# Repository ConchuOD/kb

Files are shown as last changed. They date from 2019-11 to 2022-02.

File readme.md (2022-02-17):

# Custom keyboard

Things that are sub-optimal:
- mounting holes are M2 when M3 would be better.
- SOD323 are needlessly small, requiring better soldering gear than is reasonable.

Thanks to Jorge Reyes for his simple T3.2 model: https://grabcad.com/library/teensy-3-1-3-2-1
Thanks also to Constantin for his eagle teensy models that I converted to use in kicad https://forum.pjrc.com/threads/24637-Updated-Teensy-3-1-and-Teensy-3-0-Eagle-libraries

After 2 years, I finally got myself a 3d printer. I might finally finish this :)

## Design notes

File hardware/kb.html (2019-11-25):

# G:\desktop\keyboard\kicad\kb.sch

24/11/2019 17:05:27

Eeschema (5.1.4)-1

Component Count:187

Ref | Qnty | Value | Part | Datasheet | Description | Vendor
A95, B95, BCKT95, BSLH95, C95, COLON95, COMMA95, D95, E95, EIGHT95, EQL95, ESC95, F1, F2, F3, F4, F5, F6, F7, F8, F9, F10, F11, F12, F95, FIVE95, FOUR95, FSH95, FSTOP95, G95, H95, HASH95, I95, J95, K95, L95, LSB95, M95, MINUS95, N1, N2, N3, N4, N5, N6, N7, N8, N9, N95, NDOT95, NINE95, NINUS95, NSLSH95, NSTAR95, NUMLK95, NZERO95, NZZERO95, O95, ONE95, P95, Q95, R95, RSB95, S95, SEVEN95, SIX95, T95, THREE95, TICK95, TWO95, U95, V95, W95, X95, Y95, Z95, ZERO95 | 77 | CHERRY-MX | kb:CHERRYMX_CHERRY-MX
BKSP95, TAB95 | 2 | CHERRY-MX | kb:CHERRYMX_CHERRY-MX
CAPS95 | 1 | CHERRY-MX | kb:CHERRYMX_CHERRY-MX
D1, D2, D3, D4, D5, D6, D7, D8, D9, D10, D11, D12, D13, D14, D15, D16, D17, D18, D19, D20, D21, D22, D23, D24, D25, D26, D27, D28, D29, D30, D31, D32, D33, D34, D35, D36, D37, D38, D39, D40, D41, D42, D43, D44, D45, D46, D47, D48, D49, D50, D51, D52, D53, D54, D55, D56, D57, D58, D59, D60, D61, D62, D63, D64, D65, D66, D67, D68, D69, D70, D71, D72, D73, D74, D75, D76, D77, D78, D79, D80, D81, D82, D84, D85, D86, D87, D88, D89, D90, D91, D92, D93, D94 | 93 | 1N4148WS | kb:DIODES_1N4148WS
ENTER95 | 1 | CHERRY-MX | kb:CHERRYMX_CHERRY-MX
FN95, LALT95, LCTRL95, LOS95, LSHFT95, RALT95, RCTRL95, ROS95, RSHFT95 | 9 | CHERRY-MX | kb:CHERRYMX_CHERRY-MX
NNTER95, NPLUS95 | 2 | CHERRY-MX | kb:CHERRYMX_CHERRY-MX
SPACE95 | 1 | CHERRY-MX | kb:CHERRYMX_CHERRY-MX
U$1 | 1 | TEENSY_3.1-3.2_OUTER_ROW | kb:TEENSY_3_AND_LC_SERIES_BOARDS_V1.4_TEENSY_3.1-3.2_OUTER_ROW

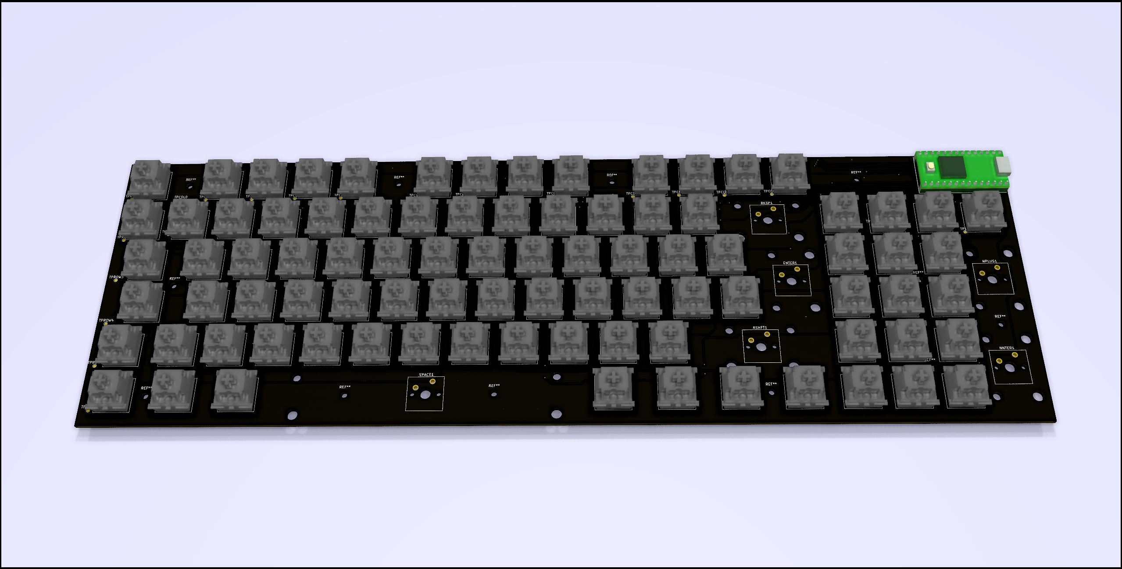
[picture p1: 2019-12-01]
hardware/kb.png

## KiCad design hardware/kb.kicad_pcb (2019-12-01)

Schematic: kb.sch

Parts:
A1: CHERRY-MX; SW_Cherry_MX_1.00u_PCB
B1: CHERRY-MX; SW_Cherry_MX_1.00u_PCB
BCKT1: CHERRY-MX; SW_Cherry_MX_1.00u_PCB
BKSP1: CHERRY-MX; SW_Cherry_MX_2.00u_PCB
BSLH1: CHERRY-MX; SW_Cherry_MX_1.00u_PCB
C1: CHERRY-MX; SW_Cherry_MX_1.00u_PCB
CAPS1: CHERRY-MX; SW_Cherry_MX_1.75u_PCB
COLON1: CHERRY-MX; SW_Cherry_MX_1.00u_PCB
COMMA1: CHERRY-MX; SW_Cherry_MX_1.00u_PCB
D1, D2, D3, D4, D5, D6, D7, D8, D9, D10, D11, D12, D13, D14, D15, D16, D17, D18, D19, D20, D21, D22, D23, D24, D25, D26, D27, D28, D29, D30, D31, D32, D33, D34, D35, D36, D37, D38, D39, D40, D41, D42, D43, D44, D45, D46, D47, D48, D49, D50, D51, D52, D53, D54, D55, D56, D57, D58, D59, D60, D61, D62, D63, D64, D65, D66, D67, D68, D69, D70, D71, D72, D73, D74, D75, D76, D77, D78, D79, D80, D81, D82, D84, D85, D86, D87, D88, D89, D90, D91, D92, D93, D94: 1N4148WS; DIODES_SOD-323
D83: CHERRY-MX; SW_Cherry_MX_1.00u_PCB
E1: CHERRY-MX; SW_Cherry_MX_1.00u_PCB
EIGHT1: CHERRY-MX; SW_Cherry_MX_1.00u_PCB
ENTER1: CHERRY-MX; SW_Cherry_MX_ISOEnter_PCB
EQL1: CHERRY-MX; SW_Cherry_MX_1.00u_PCB
ESC1: CHERRY-MX; SW_Cherry_MX_1.00u_PCB
F1, F2, F3, F4, F5, F6, F7, F8, F9, F10, F11, F12, F13: CHERRY-MX; SW_Cherry_MX_1.00u_PCB
FIVE1: CHERRY-MX; SW_Cherry_MX_1.00u_PCB
FN1: CHERRY-MX; SW_Cherry_MX_1.25u_PCB
FOUR1: CHERRY-MX; SW_Cherry_MX_1.00u_PCB
FSH1: CHERRY-MX; SW_Cherry_MX_1.00u_PCB
FSTOP1: CHERRY-MX; SW_Cherry_MX_1.00u_PCB
G1: CHERRY-MX; SW_Cherry_MX_1.00u_PCB
H1: CHERRY-MX; SW_Cherry_MX_1.00u_PCB
HASH1: CHERRY-MX; SW_Cherry_MX_1.00u_PCB
I1: CHERRY-MX; SW_Cherry_MX_1.00u_PCB
J1: CHERRY-MX; SW_Cherry_MX_1.00u_PCB
K1: CHERRY-MX; SW_Cherry_MX_1.00u_PCB
L1: CHERRY-MX; SW_Cherry_MX_1.00u_PCB
LALT1: CHERRY-MX; SW_Cherry_MX_1.25u_PCB
LCTRL1: CHERRY-MX; SW_Cherry_MX_1.25u_PCB
LOS1: CHERRY-MX; SW_Cherry_MX_1.25u_PCB
LSB1: CHERRY-MX; SW_Cherry_MX_1.00u_PCB
LSHFT1: CHERRY-MX; SW_Cherry_MX_1.25u_PCB
M1: CHERRY-MX; SW_Cherry_MX_1.00u_PCB
MINUS1: CHERRY-MX; SW_Cherry_MX_1.00u_PCB
N1, N2, N3, N4, N5, N6, N7, N8, N9, N10: CHERRY-MX; SW_Cherry_MX_1.00u_PCB
NDOT1: CHERRY-MX; SW_Cherry_MX_1.00u_PCB
NINE1: CHERRY-MX; SW_Cherry_MX_1.00u_PCB
NINUS1: CHERRY-MX; SW_Cherry_MX_1.00u_PCB
NNTER1: CHERRY-MX; SW_Cherry_MX_2.00u_Vertical_PCB
NPLUS1: CHERRY-MX; SW_Cherry_MX_2.00u_Vertical_PCB
NSLSH1: CHERRY-MX; SW_Cherry_MX_1.00u_PCB
NSTAR1: CHERRY-MX; SW_Cherry_MX_1.00u_PCB
NUMLK1: CHERRY-MX; SW_Cherry_MX_1.00u_PCB
NZERO1: CHERRY-MX; SW_Cherry_MX_1.00u_PCB
NZZERO1: CHERRY-MX; SW_Cherry_MX_1.00u_PCB
O1: CHERRY-MX; SW_Cherry_MX_1.00u_PCB
ONE1: CHERRY-MX; SW_Cherry_MX_1.00u_PCB
P1: CHERRY-MX; SW_Cherry_MX_1.00u_PCB
Q1: CHERRY-MX; SW_Cherry_MX_1.00u_PCB
R1: CHERRY-MX; SW_Cherry_MX_1.00u_PCB
RALT1: CHERRY-MX; SW_Cherry_MX_1.25u_PCB
RCTRL1: CHERRY-MX; SW_Cherry_MX_1.25u_PCB
ROS1: CHERRY-MX; SW_Cherry_MX_1.25u_PCB
RSB1: CHERRY-MX; SW_Cherry_MX_1.00u_PCB
RSHFT1: CHERRY-MX; SW_Cherry_MX_2.75u_PCB
S1: CHERRY-MX; SW_Cherry_MX_1.00u_PCB
SEVEN1: CHERRY-MX; SW_Cherry_MX_1.00u_PCB
SIX1: CHERRY-MX; SW_Cherry_MX_1.00u_PCB
SPACE1: CHERRY-MX; SW_Cherry_MX_6.25u_PCB
T1: CHERRY-MX; SW_Cherry_MX_1.00u_PCB
T32: TEENSY_3.1-3.2_DIL; TEENSY_3.0-3.2&LC_DIL
TAB1: CHERRY-MX; SW_Cherry_MX_1.50u_PCB
THREE1: CHERRY-MX; SW_Cherry_MX_1.00u_PCB
TICK1: CHERRY-MX; SW_Cherry_MX_1.00u_PCB
TP13: TestPoint; TestPoint_Pad_D1.0mm
TPCOL0, TPCOL1, TPCOL2, TPCOL3, TPCOL4, TPCOL5, TPCOL6, TPCOL7, TPCOL8, TPCOL9, TPCOL10, TPCOL11, TPCOL12: TestPoint; TestPoint_Pad_D1.0mm
TPROW0, TPROW1, TPROW2, TPROW3, TPROW4, TPROW5, TPROW6: TestPoint; TestPoint_Pad_D1.0mm
TWO1: CHERRY-MX; SW_Cherry_MX_1.00u_PCB
U1: CHERRY-MX; SW_Cherry_MX_1.00u_PCB
V1: CHERRY-MX; SW_Cherry_MX_1.00u_PCB
W1: CHERRY-MX; SW_Cherry_MX_1.00u_PCB
X1: CHERRY-MX; SW_Cherry_MX_1.00u_PCB
Y1: CHERRY-MX; SW_Cherry_MX_1.00u_PCB
Z1: CHERRY-MX; SW_Cherry_MX_1.00u_PCB
ZERO1: CHERRY-MX; SW_Cherry_MX_1.00u_PCB

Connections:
+3V3: T32.3.3V
+5V: T32.VIN
/COL0: D1.C, D2.C, D3.C, D4.C, D5.C, D6.C, D8.C, T32.0 (0/RX1/T), TPCOL0.1
/COL1: D7.C, D9.C, D10.C, D11.C, D12.C, D13.C, D14.C, T32.1 (1/TX1/T), TPCOL1.1
/COL2: D15.C, D16.C, D17.C, D18.C, D19.C, D20.C, D22.C, T32.2, TPCOL2.1
/COL3: D21.C, D24.C, D25.C, D26.C, D27.C, D28.C, D62.C, T32.3 (3/CAN-TX/PWM), TPCOL3.1
/COL4: D29.C, D30.C, D31.C, D32.C, D33.C, D34.C, D61.C, T32.4 (4/CAN-RX/PWM), TPCOL4.1
/COL5: D23.C, D35.C, D60.C, D64.C, D65.C, D66.C, D67.C, T32.5 (5/PWM), TPCOL5.1
/COL6: D36.C, D37.C, D38.C, D39.C, D40.C, D63.C, T32.6 (6/PWM), TPCOL6.1
/COL7: D42.C, D43.C, D44.C, D45.C, D46.C, T32.7 (7/RX3), TPCOL7.1
/COL8: D48.C, D49.C, D50.C, D51.C, D52.C, D53.C, T32.8 (8/TX3), TPCOL8.1
/COL9: D54.C, D55.C, D56.C, D57.C, D58.C, D59.C, D74.C, T32.9 (9/RX2/PWM), TPCOL9.1
/COL10: D69.C, D70.C, D71.C, D72.C, D77.C, D79.C, D80.C, T32.10 (10/TX2/PWM), TPCOL10.1
/COL11: D41.C, D47.C, D75.C, D76.C, D84.C, D85.C, D86.C, T32.11 (11/MOSI), TPCOL11.1
/COL12: D87.C, D88.C, D89.C, D90.C, D91.C, D92.C, T32.12 (12/MISO), TPCOL12.1
/COL13: D68.C, D73.C, D78.C, D81.C, D82.C, D93.C, D94.C, T32.13 (13/SCK/LED), TP13.1
/N$1: D1.A, ESC1.SW2 (PIN-2)
/N$2: BCKT1.SW2 (PIN-2), D2.A
/N$3: D3.A, TAB1.SW2 (PIN-2)
/N$4: CAPS1.SW2 (PIN-2), D4.A
/N$5: D5.A, LSHFT1.SW2 (PIN-2)
/N$6: D6.A, LCTRL1.SW2 (PIN-2)
/N$7: D8.A, ONE1.SW2 (PIN-2)
/N$8: D9.A, Q1.SW2 (PIN-2)
/N$9: A1.SW2 (PIN-2), D10.A
/N$10: BSLH1.SW2 (PIN-2), D11.A
/N$11: D12.A, LOS1.SW2 (PIN-2)
/N$12: D13.A, TWO1.SW2 (PIN-2)
/N$13: D14.A, W1.SW2 (PIN-2)
/N$14: D15.A, S1.SW2 (PIN-2)
/N$15: D16.A, Z1.SW2 (PIN-2)
/N$16: D17.A, LALT1.SW2 (PIN-2)
/N$17: D7.A, F1.SW2 (PIN-2)
/N$18: D19.A, THREE1.SW2 (PIN-2)
/N$19: D20.A, E1.SW2 (PIN-2)
/N$20: D21.A, D83.SW2 (PIN-2)
/N$21: D22.A, X1.SW2 (PIN-2)
/N$22: D29.A, SIX1.SW2 (PIN-2)
/N$23: D18.A, F2.SW2 (PIN-2)
/N$24: D25.A, FOUR1.SW2 (PIN-2)
/N$25: D26.A, R1.SW2 (PIN-2)
/N$26: D27.A, F13.SW2 (PIN-2)
/N$27: C1.SW2 (PIN-2), D28.A
/N$28: D35.A, Y1.SW2 (PIN-2)
/N$29: D24.A, F3.SW2 (PIN-2)
/N$30: D31.A, FIVE1.SW2 (PIN-2)
/N$31: D32.A, T1.SW2 (PIN-2)
/N$32: D33.A, G1.SW2 (PIN-2)
/N$33: D34.A, V1.SW2 (PIN-2)
/N$34: D60.A, H1.SW2 (PIN-2)
/N$35: D30.A, F4.SW2 (PIN-2)
/N$36: D37.A, EIGHT1.SW2 (PIN-2)
/N$37: D38.A, I1.SW2 (PIN-2)
/N$38: D39.A, K1.SW2 (PIN-2)
/N$39: D40.A, M1.SW2 (PIN-2)
/N$40: D41.A, NUMLK1.SW2 (PIN-2)
/N$41: D36.A, F7.SW2 (PIN-2)
/N$42: D43.A, NINE1.SW2 (PIN-2)
/N$43: D44.A, O1.SW2 (PIN-2)
/N$44: D45.A, L1.SW2 (PIN-2)
/N$45: COMMA1.SW2 (PIN-2), D46.A
/N$46: D47.A, NZERO1.SW2 (PIN-2)
/N$47: D42.A, F8.SW2 (PIN-2)
/N$48: D49.A, ZERO1.SW2 (PIN-2)
/N$49: D50.A, P1.SW2 (PIN-2)
/N$50: COLON1.SW2 (PIN-2), D51.A
/N$51: D52.A, FSTOP1.SW2 (PIN-2)
/N$52: D53.A, RALT1.SW2 (PIN-2)
/N$53: D48.A, F9.SW2 (PIN-2)
/N$54: D55.A, MINUS1.SW2 (PIN-2)
/N$55: D56.A, LSB1.SW2 (PIN-2)
/N$56: D57.A, TICK1.SW2 (PIN-2)
/N$57: D58.A, FSH1.SW2 (PIN-2)
/N$58: D59.A, ROS1.SW2 (PIN-2)
/N$59: D54.A, F10.SW2 (PIN-2)
/N$60: B1.SW2 (PIN-2), D61.A
/N$61: D62.A, SPACE1.SW2 (PIN-2)
/N$62: D23.A, F5.SW2 (PIN-2)
/N$63: D64.A, SEVEN1.SW2 (PIN-2)
/N$64: D65.A, U1.SW2 (PIN-2)
/N$65: D66.A, J1.SW2 (PIN-2)
/N$66: D67.A, N10.SW2 (PIN-2)
/N$67: D68.A, NDOT1.SW2 (PIN-2)
/N$68: D63.A, F6.SW2 (PIN-2)
/N$69: D70.A, EQL1.SW2 (PIN-2)
/N$70: D71.A, RSB1.SW2 (PIN-2)
/N$71: D72.A, HASH1.SW2 (PIN-2)
/N$72: D78.A, NPLUS1.SW2 (PIN-2)
/N$73: D74.A, FN1.SW2 (PIN-2)
/N$74: D69.A, F11.SW2 (PIN-2)
/N$75: BKSP1.SW2 (PIN-2), D76.A
/N$76: D77.A, ENTER1.SW2 (PIN-2)
/N$77: D81.A, N9.SW2 (PIN-2)
/N$78: D79.A, RSHFT1.SW2 (PIN-2)
/N$79: D80.A, RCTRL1.SW2 (PIN-2)
/N$80: D75.A, F12.SW2 (PIN-2)
/N$81: D82.A, N6.SW2 (PIN-2)
/N$83: D84.A, N7.SW2 (PIN-2)
/N$84: D85.A, N4.SW2 (PIN-2)
/N$85: D86.A, N1.SW2 (PIN-2)
/N$86: D93.A, N3.SW2 (PIN-2)
/N$87: D88.A, NSLSH1.SW2 (PIN-2)
/N$88: D89.A, N8.SW2 (PIN-2)
/N$89: D90.A, N5.SW2 (PIN-2)
/N$90: D91.A, N2.SW2 (PIN-2)
/N$91: D92.A, NZZERO1.SW2 (PIN-2)
/N$92: D87.A, NSTAR1.SW2 (PIN-2)
/N$93: D94.A, NNTER1.SW2 (PIN-2)
/N$94: D73.A, NINUS1.SW2 (PIN-2)
/ROW0: ESC1.SW1 (PIN-1), F1.SW1 (PIN-1), F2.SW1 (PIN-1), F3.SW1 (PIN-1), F4.SW1 (PIN-1), F5.SW1 (PIN-1), F6.SW1 (PIN-1), F8.SW1 (PIN-1), F9.SW1 (PIN-1), F10.SW1 (PIN-1), F11.SW1 (PIN-1), F12.SW1 (PIN-1), NINUS1.SW1 (PIN-1), NSTAR1.SW1 (PIN-1), T32.17/A3 (17/A3/T), TPROW0.1
/ROW1: BKSP1.SW1 (PIN-1), EQL1.SW1 (PIN-1), F7.SW1 (PIN-1), FIVE1.SW1 (PIN-1), FOUR1.SW1 (PIN-1), MINUS1.SW1 (PIN-1), NINE1.SW1 (PIN-1), NPLUS1.SW1 (PIN-1), NSLSH1.SW1 (PIN-1), ONE1.SW1 (PIN-1), SEVEN1.SW1 (PIN-1), T32.18/A4 (18/A4/T/SDA0), THREE1.SW1 (PIN-1), TPROW1.1, TWO1.SW1 (PIN-1), ZERO1.SW1 (PIN-1)
/ROW2: BCKT1.SW1 (PIN-1), E1.SW1 (PIN-1), EIGHT1.SW1 (PIN-1), LSB1.SW1 (PIN-1), N8.SW1 (PIN-1), N9.SW1 (PIN-1), NUMLK1.SW1 (PIN-1), O1.SW1 (PIN-1), P1.SW1 (PIN-1), R1.SW1 (PIN-1), RSB1.SW1 (PIN-1), SIX1.SW1 (PIN-1), T32.19/A5 (19/A5/T/SCL0), TPROW2.1, W1.SW1 (PIN-1), Y1.SW1 (PIN-1)
/ROW3: COLON1.SW1 (PIN-1), D83.SW1 (PIN-1), ENTER1.SW1 (PIN-1), I1.SW1 (PIN-1), L1.SW1 (PIN-1), N5.SW1 (PIN-1), N6.SW1 (PIN-1), N7.SW1 (PIN-1), Q1.SW1 (PIN-1), S1.SW1 (PIN-1), T1.SW1 (PIN-1), T32.20/A6 (20/A6/PWM), TAB1.SW1 (PIN-1), TICK1.SW1 (PIN-1), TPROW3.1, U1.SW1 (PIN-1)
/ROW4: A1.SW1 (PIN-1), CAPS1.SW1 (PIN-1), COMMA1.SW1 (PIN-1), F13.SW1 (PIN-1), FSH1.SW1 (PIN-1), FSTOP1.SW1 (PIN-1), G1.SW1 (PIN-1), H1.SW1 (PIN-1), HASH1.SW1 (PIN-1), K1.SW1 (PIN-1), N2.SW1 (PIN-1), N3.SW1 (PIN-1), N4.SW1 (PIN-1), T32.21/A7 (21/A7/PWM), TPROW4.1, Z1.SW1 (PIN-1)
/ROW5: BSLH1.SW1 (PIN-1), C1.SW1 (PIN-1), J1.SW1 (PIN-1), LSHFT1.SW1 (PIN-1), M1.SW1 (PIN-1), N1.SW1 (PIN-1), NNTER1.SW1 (PIN-1), NZZERO1.SW1 (PIN-1), RALT1.SW1 (PIN-1), ROS1.SW1 (PIN-1), RSHFT1.SW1 (PIN-1), T32.22/A8 (22/A8/T/PWM), TPROW5.1, V1.SW1 (PIN-1), X1.SW1 (PIN-1)
/ROW6: B1.SW1 (PIN-1), FN1.SW1 (PIN-1), LALT1.SW1 (PIN-1), LCTRL1.SW1 (PIN-1), LOS1.SW1 (PIN-1), N10.SW1 (PIN-1), NDOT1.SW1 (PIN-1), NZERO1.SW1 (PIN-1), RCTRL1.SW1 (PIN-1), SPACE1.SW1 (PIN-1), T32.23/A9 (23/A9/T/PWM), TPROW6.1
GND: T32.AGND, T32.GND

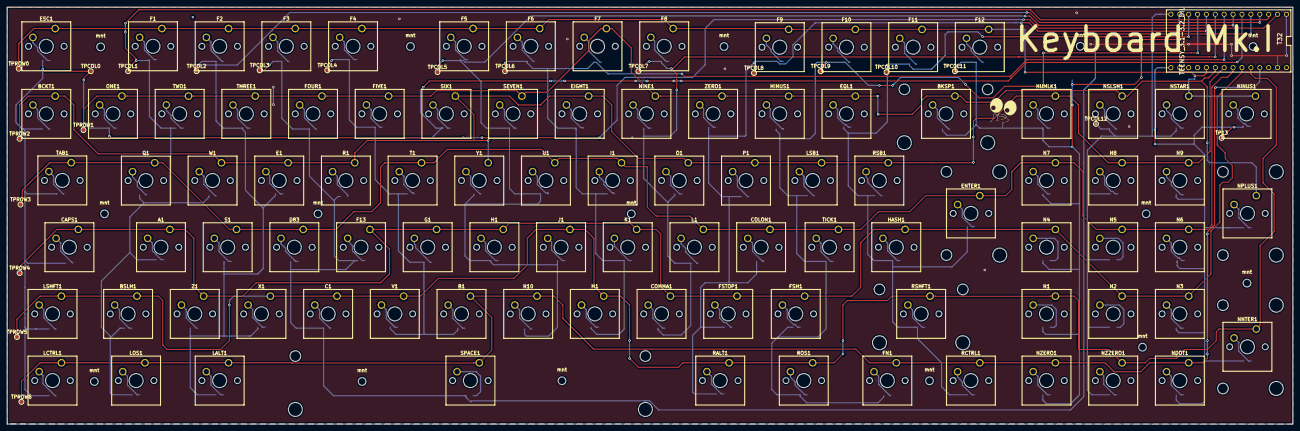
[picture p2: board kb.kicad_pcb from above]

Board: 2 copper layers, 367.3 x 119.1 mm, 223 parts (0 on the bottom side), 115 nets.

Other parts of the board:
mnt: MountingHole_2.2mm_M2
mnt#2, mnt#3, mnt#4, mnt#5, mnt#6, mnt#7, mnt#8, mnt#9, mnt#10, mnt#11, mnt#12, mnt#13, mnt#14, mnt#15: MountingHole_2.2mm_M2

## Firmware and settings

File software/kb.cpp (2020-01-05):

/* includes */
#include "tester.h"
#include "kb_matrix.h"
#include <Arduino.h>
#include "usb_kb.h"

/* defines */
#define SERIAL_BAUD_RATE 115200
#define DEBOUNCE_COUNT   4

int main(void)
{
    uint8_t row_inc, col_inc;
    uint8_t keyboard_matrix[NUM_COLS][NUM_ROWS], pressed[NUM_COLS][NUM_ROWS];
    uint8_t debounce;
    uint8_t mask = (1UL << DEBOUNCE_COUNT) - 1UL;

    /* Setup code */
    sei(); // enable interupts
#ifdef USB_SERIAL
    Serial.begin(SERIAL_BAUD_RATE); // enable USB serial for tests
    while (!Serial){}
    Serial.println("Starting program");
#endif /* USB_SERIAL */

    setup_teensy_ports(); // set up GPIOs for keyboard matrix

    for (col_inc = 0; col_inc < NUM_COLS; col_inc++)
    {
        for (row_inc = 0; row_inc < NUM_ROWS; row_inc++)
        {
            keyboard_matrix[col_inc][row_inc] = LOW;
        }
    }

    /* Main loop */
    for (; /*ever*/;)
    {
        for (col_inc = 0; col_inc < NUM_COLS; col_inc++)
        {
            digitalWriteFast(COL0_PIN + col_inc, LOW); // short to ground
            for (row_inc = 0; row_inc < NUM_ROWS; row_inc++)
            {
                //debounce for n cycles
                keyboard_matrix[col_inc][row_inc] <<= 1UL;
                keyboard_matrix[col_inc][row_inc] |= (!digitalRead(ROW0_PIN + row_inc));
            } // row increment
            digitalWriteFast(COL0_PIN + col_inc, HIGH); // high Z
            delayMicroseconds(10);
        } // column increment

        for (row_inc = 0; row_inc < NUM_ROWS; row_inc++)
        {
            for (col_inc = 0; col_inc < NUM_COLS; col_inc++)
            {
                debounce = keyboard_matrix[col_inc][row_inc] & mask;                
                pressed[col_inc][row_inc] <<= 1UL;
                pressed[col_inc][row_inc] |= 1UL & (debounce == mask);

                if (pressed[col_inc][row_inc] & 1UL) // if 
                {
                    Kb.press_custom(matrix_to_keycode[col_inc * NUM_ROWS + row_inc]);
                }
                else if (pressed[col_inc][row_inc] & 2UL) // if most recent was zero but previous 1
                {
                    Kb.release_custom(matrix_to_keycode[col_inc * NUM_ROWS + row_inc]);
                }
            } // row increment
        } // column increment
    } // for ever
} // main

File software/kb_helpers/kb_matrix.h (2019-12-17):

#ifndef KB_MATRIX_H_
#define KB_MATRIX_H_

#include <kinetis.h>
#include <Arduino.h>
#include "keycodes.h"

#define COL0_PIN  0
#define COL1_PIN  1
#define COL2_PIN  2
#define COL3_PIN  3
#define COL4_PIN  4
#define COL5_PIN  5
#define COL6_PIN  6
#define COL7_PIN  7
#define COL8_PIN  8
#define COL9_PIN  9
#define COL10_PIN 10
#define COL11_PIN 11
#define COL12_PIN 12
#define COL13_PIN 13

#define ROW0_PIN  17
#define ROW1_PIN  18
#define ROW2_PIN  19
#define ROW3_PIN  20
#define ROW4_PIN  21
#define ROW5_PIN  22
#define ROW6_PIN  23

#define NUM_ROWS  7
#define NUM_COLS  14

static const uint16_t matrix_to_keycode[NUM_ROWS * NUM_COLS] = {
    KC_ESC,   KC_ONE,   KC_BTK,   KC_TAB,    KC_CAPS,  KC_LSHFT, KC_LCTRL,
    KC_F1,    KC_TWO,   KC_W,     KC_Q,      KC_A,     KC_BSLH,  KC_LOS,
    KC_F2,    KC_THREE, KC_E,     KC_S,      KC_Z,     KC_X,     KC_LALT,
    KC_F3,    KC_FOUR,  KC_R,     KC_D,      KC_F,     KC_C,     KC_SPACE,
    KC_F4,    KC_FIVE,  KC_SIX,   KC_T,      KC_G,     KC_V,     KC_B,
    KC_F5,    KC_SEVEN, KC_Y,     KC_U,      KC_H,     KC_J,     KC_N,
    KC_F6,    KC_F7,    KC_EIGHT, KC_I,      KC_K,     KC_M,     0,
    KC_F8,    KC_NINE,  KC_O,     KC_L,      KC_COMMA, 0,        0,
    KC_F9,    KC_ZERO,  KC_P,     KC_SCOLON, KC_DOT,   KC_RALT,  0,
    KC_F10,   KC_MINUS, KC_LSB,   KC_TICK,   KC_FSLSH, KC_ROS,   KC_RCTRL,
    KC_F11,   KC_EQUAL, KC_RSB,   KC_ENTER,  KC_HASH,  KC_RSHFT, KC_RCTRL,
    KC_F12,   KC_BKSP,  KC_NUMLK, KC_N7,     KC_N4,    KC_N1,    KC_N0,
    KC_NSTAR, KC_NSLSH, KC_N8,    KC_N5,     KC_N2,    KC_N0,    0,
    KC_NINUS, KC_NPLUS, KC_N9,    KC_N6,     KC_N3,    KC_NNTER, KC_NDOT
};

void setup_teensy_ports(void);

#endif /* KB_MATRIX_H_ */

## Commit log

2019-11-25 initial commit for custom kb
    [kb - Copy.sch, kb-2019-11-24-00-39-25.sch, kb.brd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]
2019-11-25 more routing
    [kb.kicad_pcb]
2019-11-28 routing done
    [kb - Copy.sch, kb-2019-11-24-00-39-25.sch, kb.brd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]
2019-12-01 ready for manuf.
    [kb.kicad_pcb]
2019-12-10 moving labels on T32
    [kb.sch]
2019-12-11 kicad/ -> hardware/
    [kb-B_Mask.gbs, kb-B_Paste.gbp, kb-B_SilkS.gbo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]
2019-12-11 adding teensy cores submodule
2019-12-11 attempting to make cores submodule track master directly
2019-12-17 pending exposal of keycode related functions to avoid pjrc supplied unicode based stuff - just do my own extention of stream
    [kb.cpp, tester.cpp]
2020-01-05 update tcores and rename files to avoid conflict with tcores provided usb keyboard
    [kb.cpp]
